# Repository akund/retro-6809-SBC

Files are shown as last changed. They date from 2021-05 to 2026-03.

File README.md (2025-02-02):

# retro-6809-SBC
6809 based single board computer (more product info on [Tindie](https://www.tindie.com/products/akund/bare-retro-6809-sbc-pcb-only/))

This library is free software. - WITHOUT ANY WARRANTY -

2018-2023 Adrian Kundert. [adrian.kundert@gmail.com](mailto:adrian.kundert@gmail.com)  

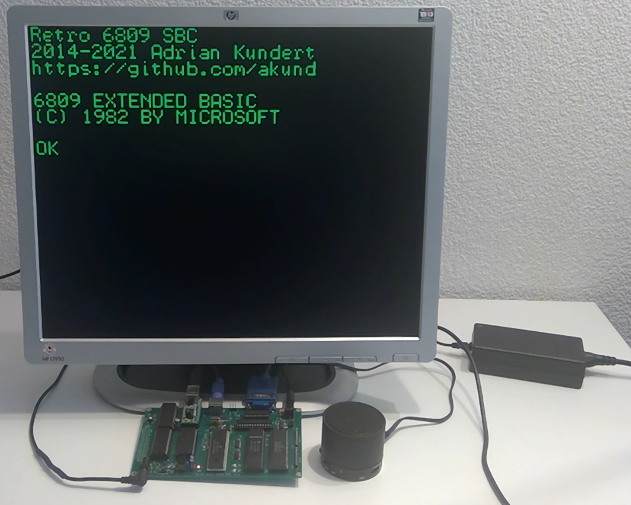
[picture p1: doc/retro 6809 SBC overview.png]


The [retro 6809 SBC](doc/Retro_6809_SBC.pdf) is a homebrew 8-bit computer running BASIC as in the 80's but with sound and more modern peripherals like PS/2 keyboard, VGA output and SD card.
The system has 32 KB RAM for a MPU clocked at 8 MHz. The Audio/Video and Keyboard peripherals are implemented by an ATmega328 ([APL](https://github.com/akund/APL)).

# Features Overview
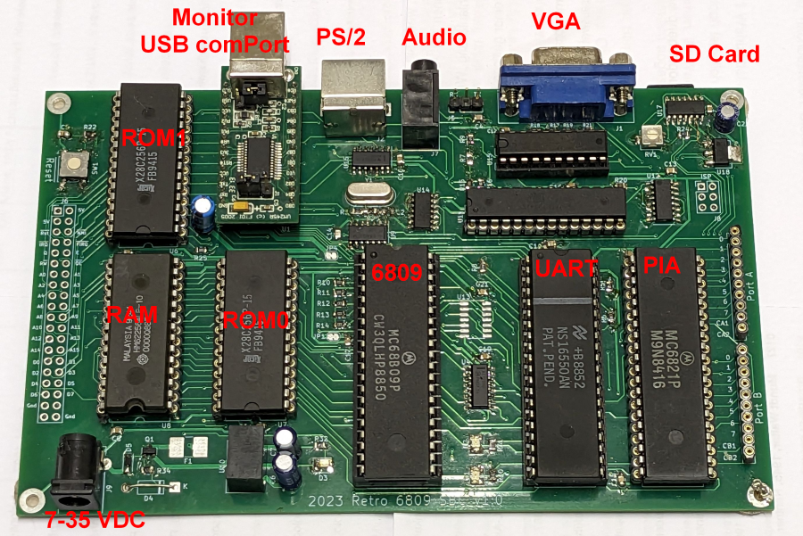
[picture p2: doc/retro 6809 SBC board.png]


# Demo

## Microsoft Color Computer Extended Basic (reworked source code based on [Grant Searle](http://searle.x10host.com/6809/Simple6809.html)) .
## Color Computer Disk Basic (the FAT32 SD card implmentation is based on CC Dharmani ExploreEmbedded) 
### Included tokens
#### (From the Color BASIC ROM)

FOR, GO, REM, ELSE, IF, DATA, PRINT, ON GOSUB, ON GOTO, INPUT, LINE INPUT, END, NEXT, DIM, READ, RUN, RESTORE, RETURN, STOP, POKE, CONT, LIST, CLEAR, SET, CLS, SOUND, NEW, EXEC, TAB, TO, SUB, THEN, NOT, STEP, +, -, *, /, ^, AND, OR, >, =, <

#### (From the Extended BASIC ROM)

DEL, DEF, LET, RENUM, FN, USING, &, &H, TRON, TROFF, EDIT

#### (From the Disk BASIC ROM)

DIR, LOAD, SAVE, KILL

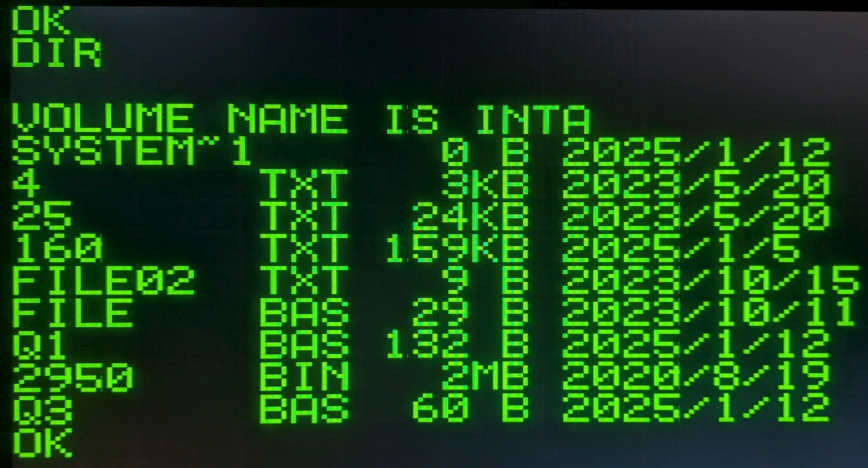
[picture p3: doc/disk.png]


#### (added to the BASIC commands)

DATE, TIME

### Secondary functions

#### (From the Color BASIC ROM)
SGN, INT, ABS, USR, RND, SIN, PEEK, LEN, STR$, VAL, ASC, CHR$, LEFT$, RIGHT$, MID$, INKEY$, MEM

#### (From the Extended BASIC ROM)
ATN, COS, TAN, EXP, FIX, LOG, SQR, HEX$, VARPTR, INSTR, STRING$, MID$ (MODIFICATION), POS

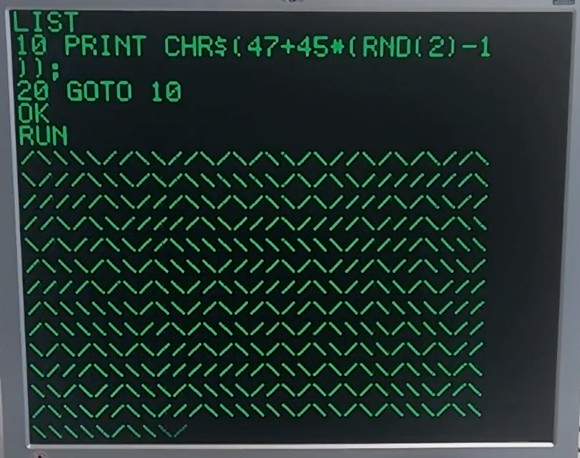
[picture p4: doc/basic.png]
[](https://www.youtube.com/watch?v=NazOm493rk8)

The BASIC commands can be entered with the keyboard at the prompt or from Terminal (see below)

## Monitor usage with the Terminal
The Monitor is an assistance tool for debugging by accessign the memory and sending BASIC command (override the keyboard).
By the Terminal command "h\r" the Help Menu is shown.
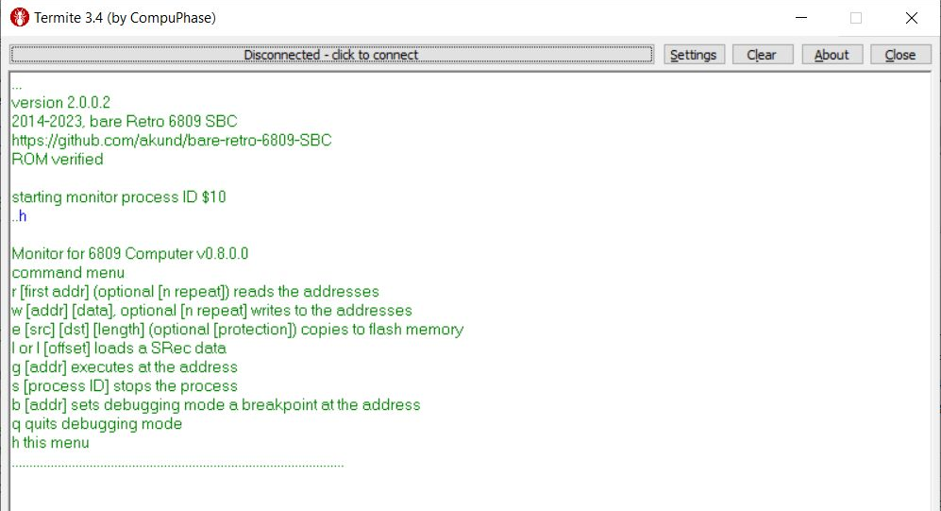
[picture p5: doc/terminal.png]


1. A [BASIC file](basic/pong.bas) can be send to the retro 6809 SBC with the command "L"
a message "send now the BAS file" is prompt before you can send the BASIC file.

2. A SREC file can be loaded in the memory with the command "l\r" and then execute "g\r".
Important when another program is loaded, the command "S 20\r" is required free the RAM occupied by the BASIC process (ID 0x20).
As an example, the program [SOKOBAN](app/sokobanC.s19) starting at adress 0x2000 is loaded ("l\r") into the RAM and executed ("g 2000\r").
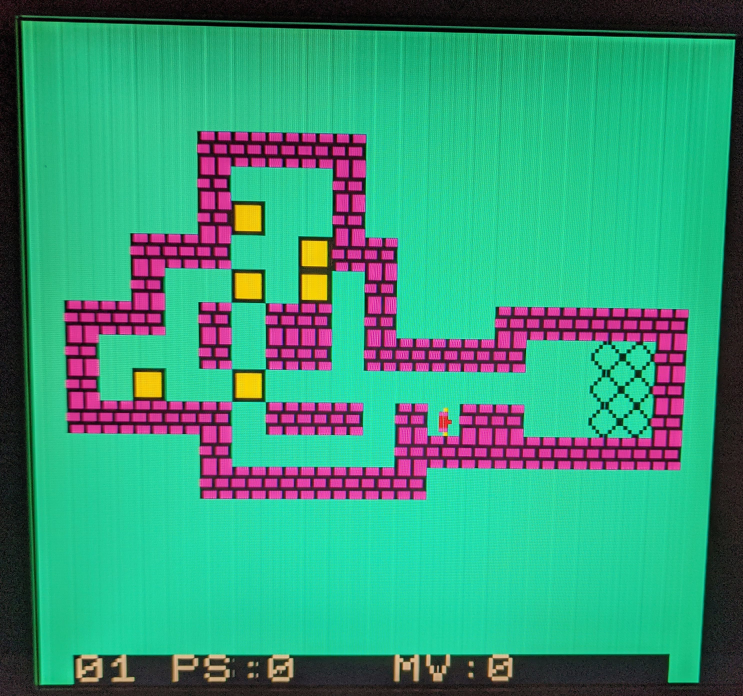
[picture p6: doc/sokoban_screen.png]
[](https://www.youtube.com/watch?v=ke1KYbIA_8k)

Another example, the demo program [SD_CARD](app/demoSD_C.s19) starting at adress 0x2000 is loaded ("l\r") into the RAM and executed ("g 2000\r").

main() {

	char* pData, filename; 
	if(initDISK() != 0) return;	
	dir();	
	filename = "FILE.TXT";
	pData = "hello SDcard";
	writefile(filename, pData);
	readfile(filename);
	deletefile(filename);
}

## C cross-compiler
The PC application "mc.exe" is an ANSI C89 cross-compiler for program written in C targeting the 6809 MPU.

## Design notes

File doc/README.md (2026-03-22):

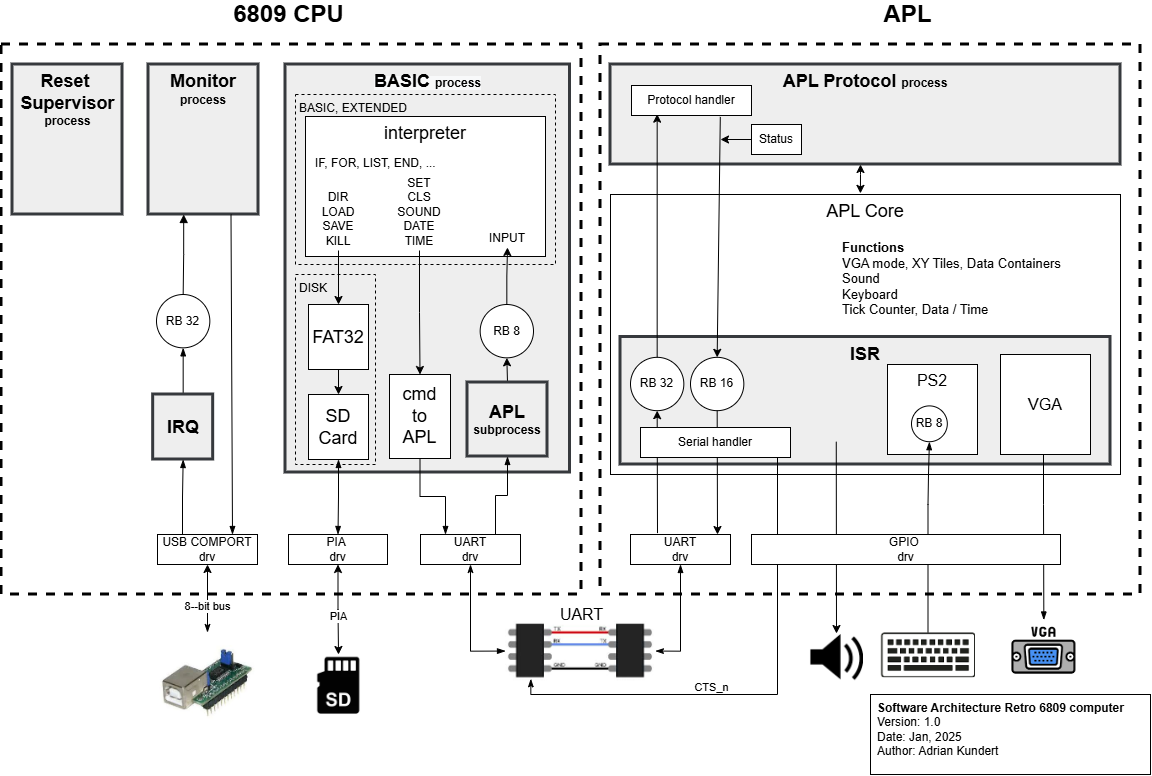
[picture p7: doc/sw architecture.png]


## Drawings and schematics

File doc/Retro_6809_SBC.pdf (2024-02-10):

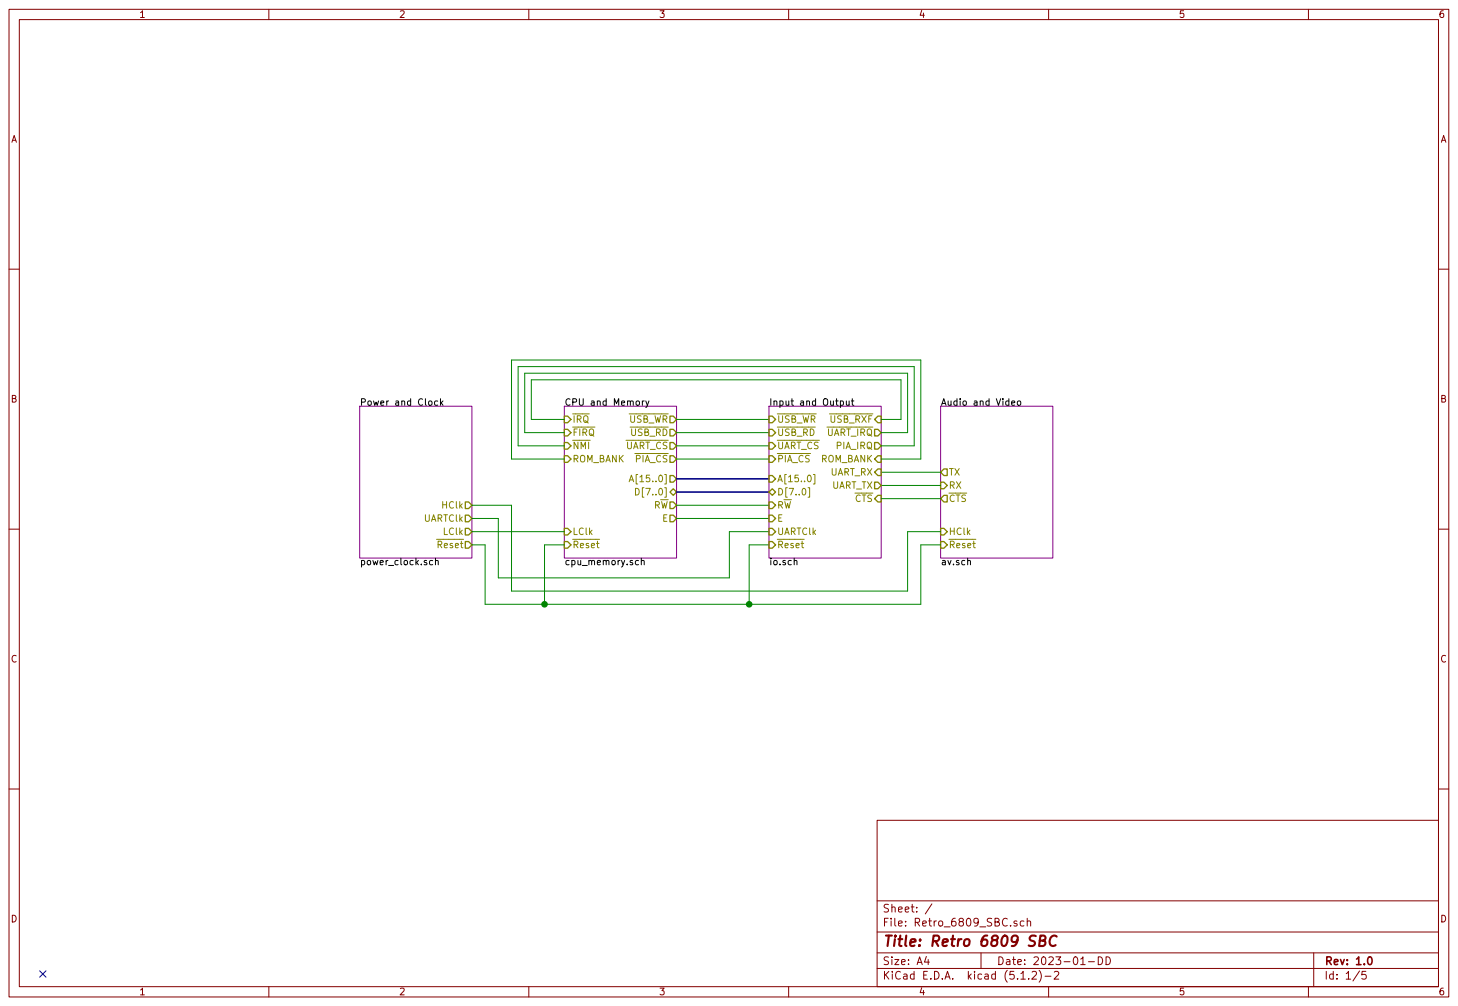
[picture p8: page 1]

TXHClk CTS
av.sch Reset RX

File: Retro_6809_SBC.sch Sheet: /
Id: 1/5 Title: Retro 6809 SBC

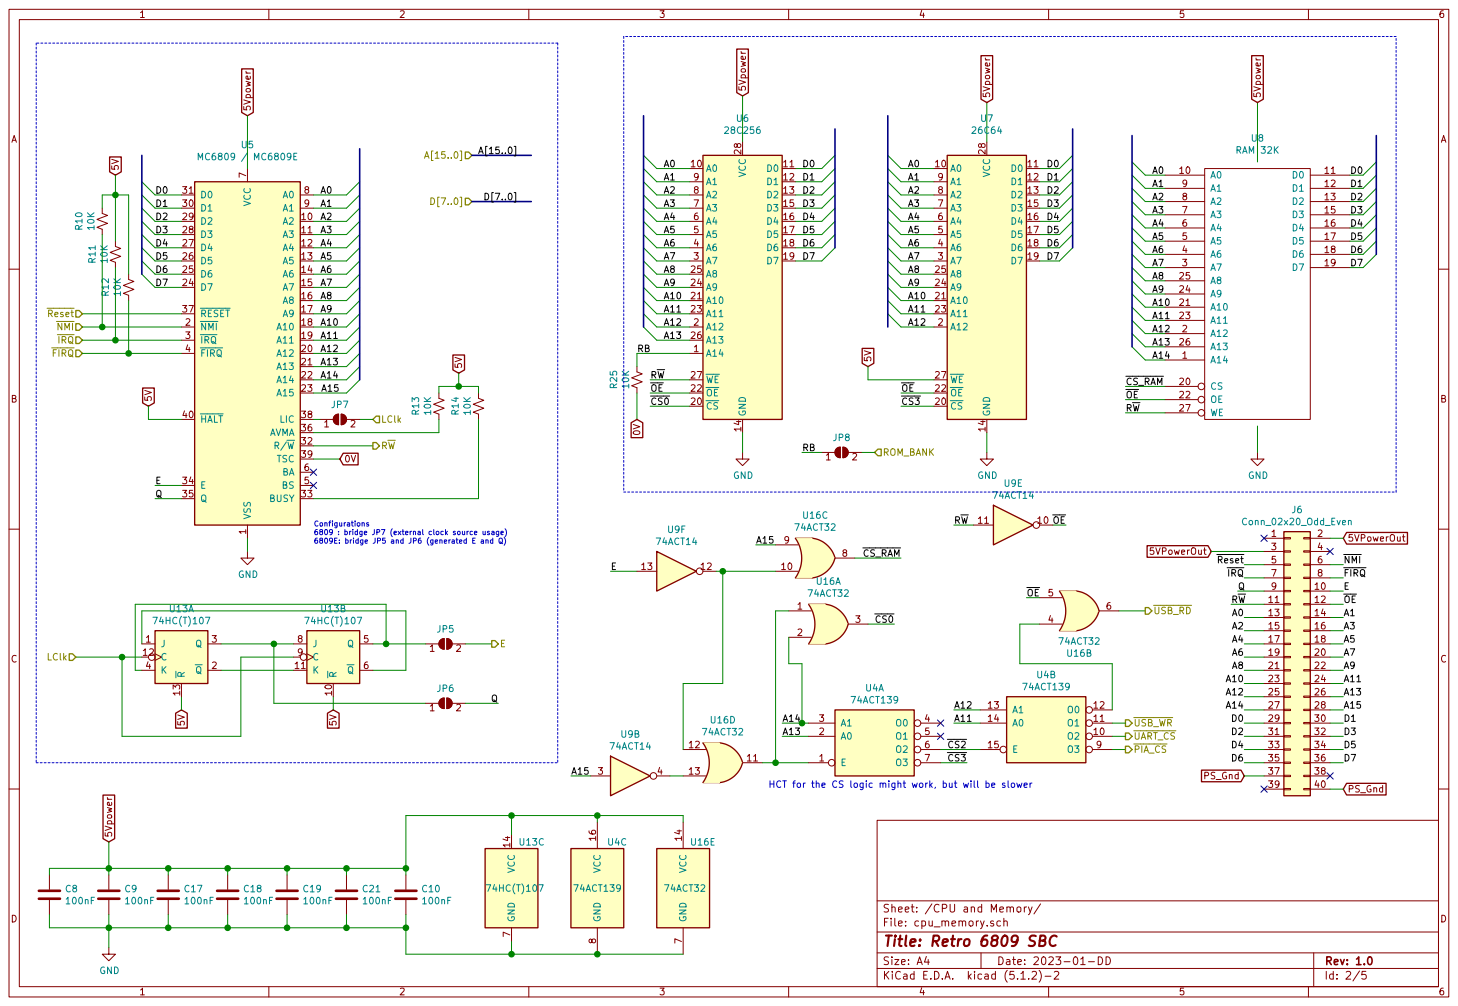
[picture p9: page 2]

HCT for the CS logic might work, but will be slower C8

Sheet: /CPU and Memory/
File: cpu_memory.sch
Id: 2/5 Title: Retro 6809 SBC

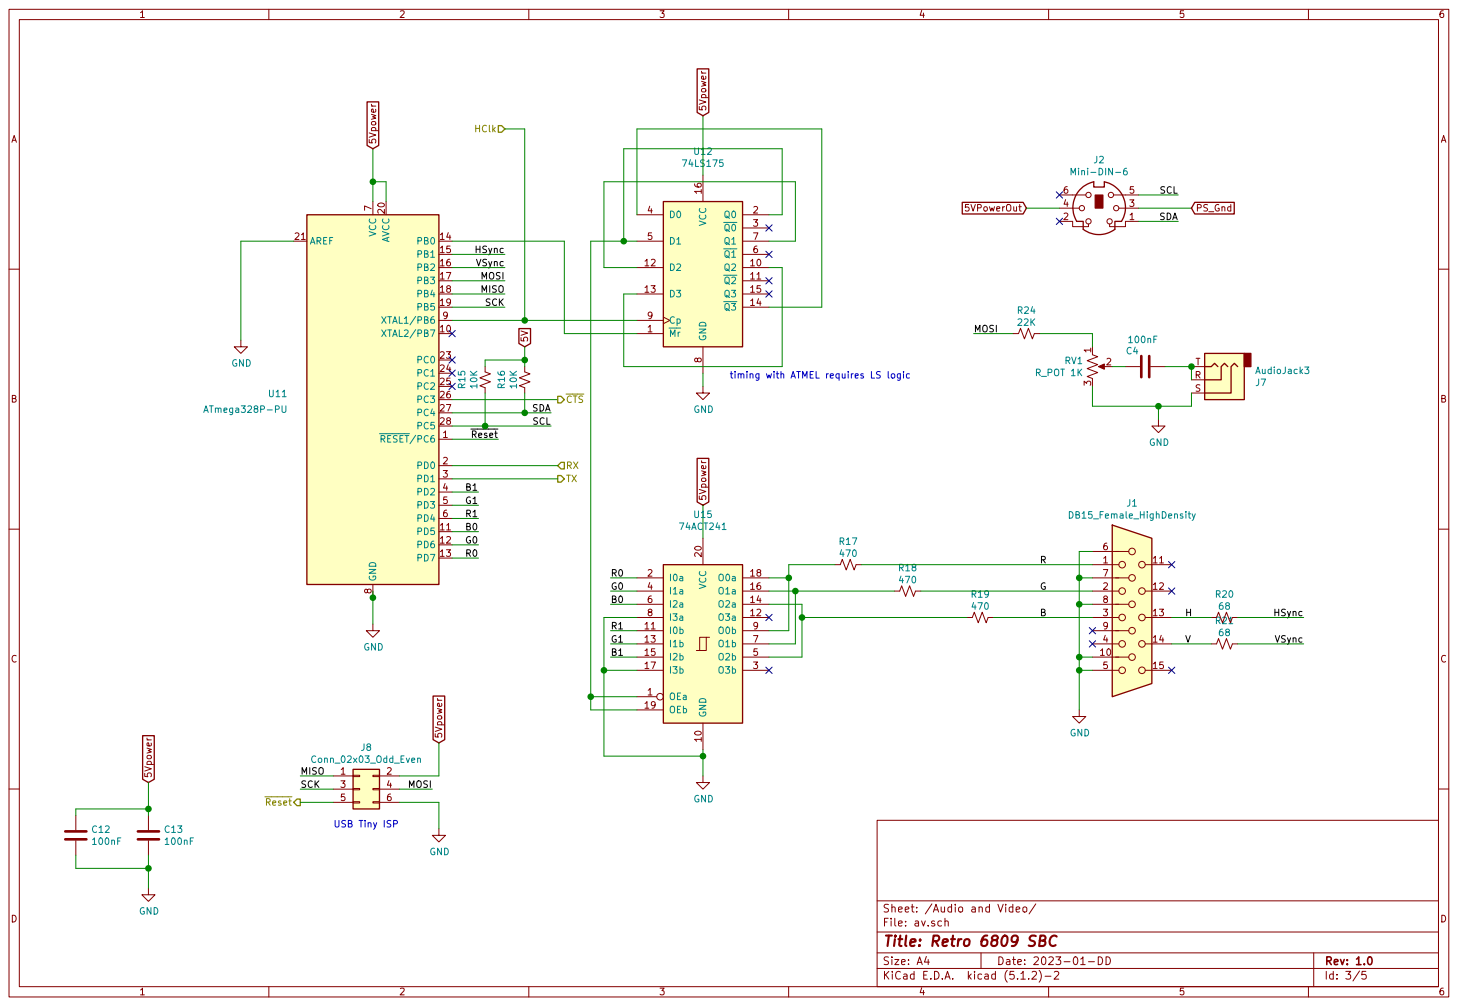
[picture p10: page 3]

8 XTAL1/PB6 9 U11 ATmega328P-PU Mr 1 Q2 10 Q2 11 D2 12 D3 13 Q3 14 Q3 15 VCC 16 Q0 2 Q0 3 D0 4 D1 5 Q1 6 Q1 7 GND

timing with ATMEL requires LS logic

File: av.sch Sheet: /Audio and Video/
Id: 3/5 Title: Retro 6809 SBC

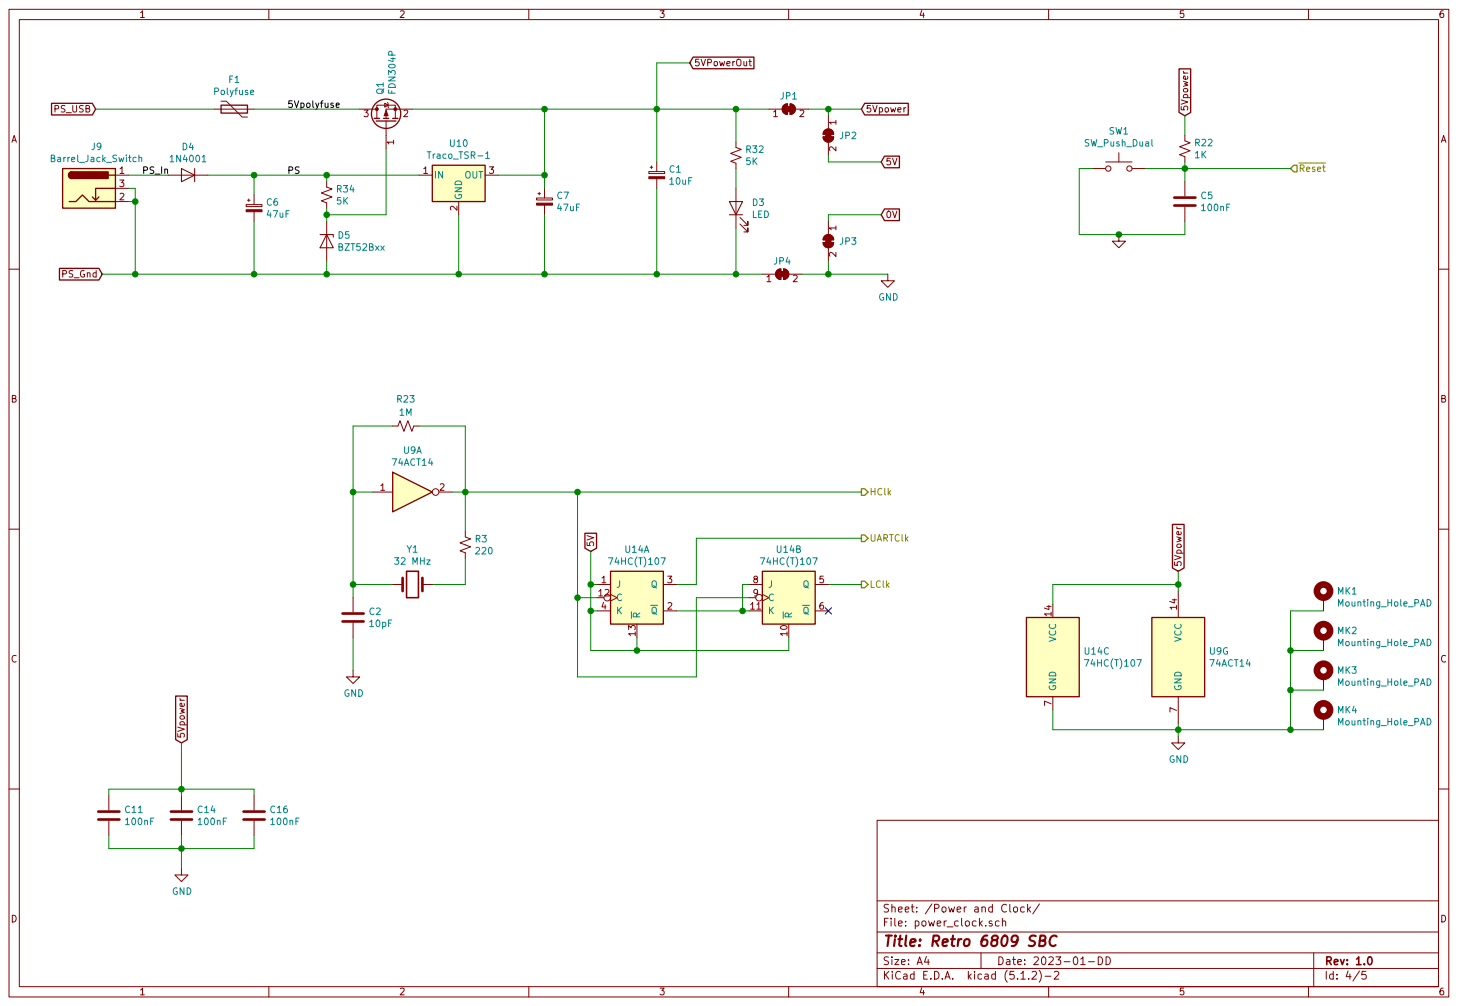
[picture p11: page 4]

File: power_clock.sch Sheet: /Power and Clock/
Id: 4/5 Title: Retro 6809 SBC

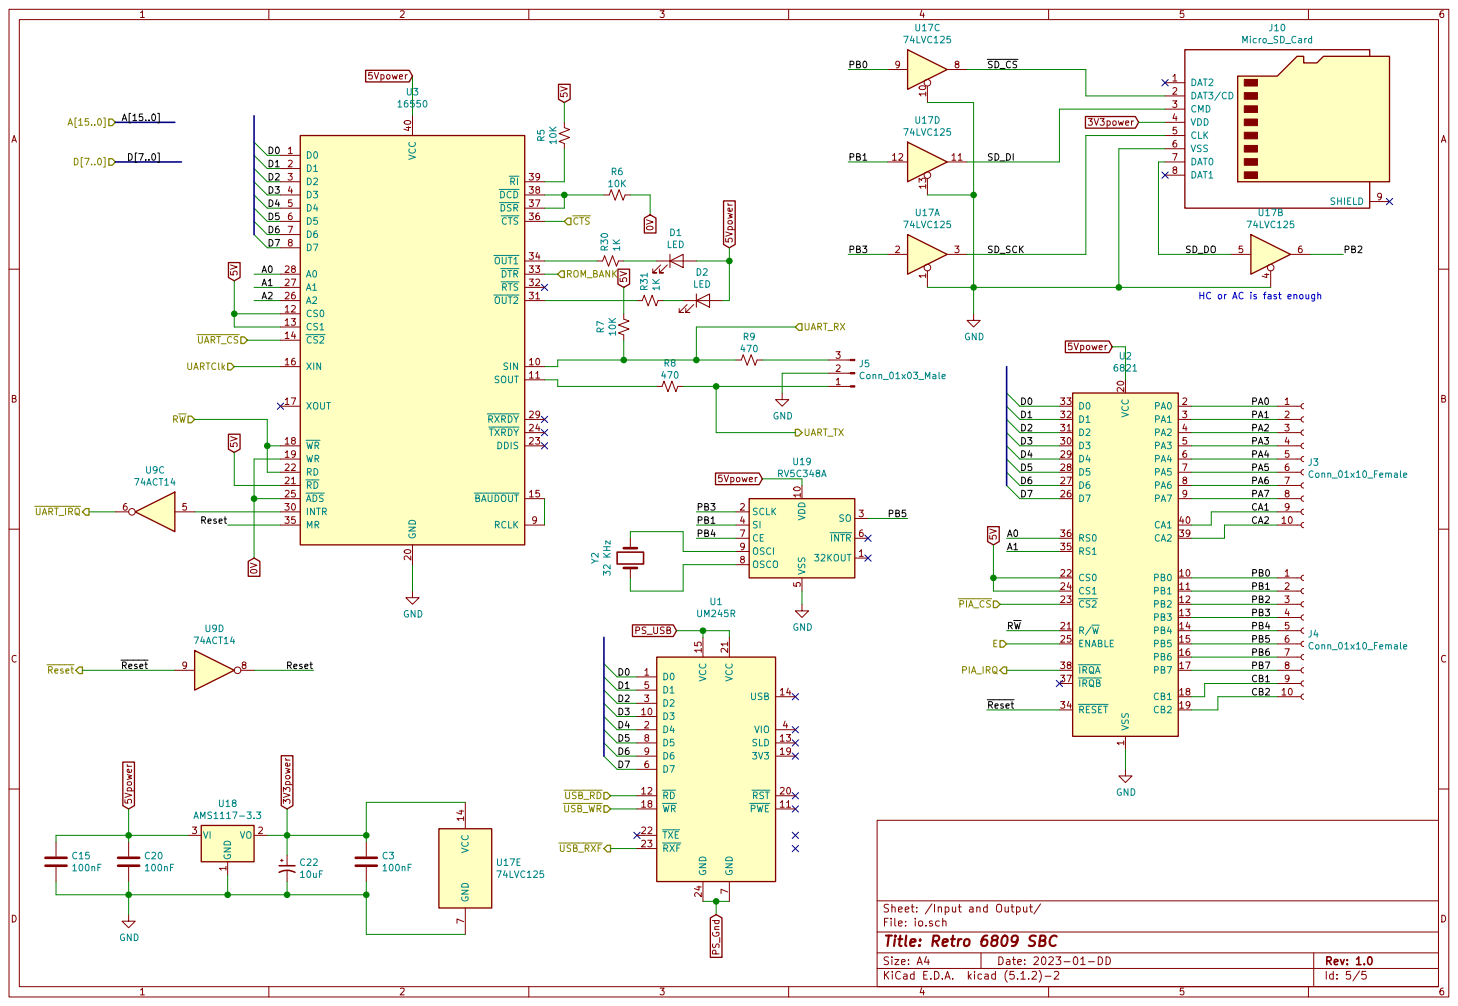
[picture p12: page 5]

HC or AC is fast enough

File: io.sch Sheet: /Input and Output/
Id: 5/5 Title: Retro 6809 SBC

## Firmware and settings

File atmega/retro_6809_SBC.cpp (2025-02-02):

/***************************************************************************************************/
/*                                                                                                 */
/* file:          retro_6809_SBC.ino                                                               */
/*                                                                                                 */
/* source:        2020, written by Adrian Kundert (adrian.kundert@gmail.com)                       */
/*                                                                                                 */
/* description:   Retro 6809 SBC application                                                       */
/*                                                                                                 */
/* This library is free software; you can redistribute it and/or modify it under the terms of the  */
/* GNU Lesser General Public License as published by the Free Software Foundation;                 */
/* either version 2.1 of the License, or (at your option) any later version.                       */
/*                                                                                                 */
/* This library is distributed in the hope that it will be useful, but WITHOUT ANY WARRANTY;       */
/* without even the implied warranty of MERCHANTABILITY or FITNESS FOR A PARTICULAR PURPOSE.       */
/* See the GNU Lesser General Public License for more details.                                     */
/*                                                                                                 */
/***************************************************************************************************/

#include "config.h"
#include "APLcore.h"
#include "APLtile.h"
#ifdef ATMEL_STUDIO
	#include <avr/pgmspace.h>
	#include <avr/io.h>
	#include <avr/boot.h>
	#include <avr/interrupt.h>
#endif


#pragma GCC optimize ("-O3") // speed optimization gives more deterministic behavior

BOOTLOADER_SECTION void boot_program_page(unsigned long int page, unsigned char *buf); // declared as unrewritable section

const char SwVersion[] PROGMEM = "sw v1.2.0.0\r";

APLcore INSTANCE;
APLcore* pAPL = 0;

const uint8_t Container_Size = TileMemSize;

// programmable PGM tiles for custom rendering
const uint8_t PGM_Container_index_OFFSET = 0x80;
const uint8_t PGM_Container_COUNT = 32;
const unsigned char PGM_Container[PGM_Container_COUNT*Container_Size] __attribute__((aligned(SPM_PAGESIZE))) PROGMEM = {};

// programmable RAM tiles for custom rendering
const uint8_t RAM_Container_index_OFFSET = 0xE0;
const uint8_t RAM_Container_COUNT = 10;
uint8_t RAM_Container[RAM_Container_COUNT][Container_Size];

uint8_t  tileScroll, x, y, MAX_X, MAX_Y;
bool textMode;

// screen cursor state
#define CURSOR_BLINKING 'b'
#define CURSOR_ON       '1'
#define CURSOR_OFF      '0'

// keyboard data
#define KB_DATA 3
char kbStr[6];

// APL status
#define APL_RESET     '0'
#define APL_READY     '1'
#define APL_BUSY      '2'
#define APL_UNDEFINED '9'
#define APL_STATUS_BYTE 2
char statusStr[5];
unsigned long t;
    
/*
 * Protocol format
[Direction ][ body ][ end]
['D' or 'U' ]  [ body]  [ '\r' ]

Body [cmd] [len] [data ....]
video command(s)
  - Cursor blink/on/off -> 'c', ('b' or '1' or '0'), '\r'
  - Position xy         -> 'p', x+'0', y+'0', '\r'     
  - scRoll              -> 'r', n+'0', '\r'            
  - putFontchar         -> 'f', length, value0, value1, ... value_length-1, '\r'
  - cLearscreen         -> 'l', color+'0', '\r'
  - setTile             -> 't', length+'0', index0, index1, ... , index_length-1, '\r'	; PETSCII character set (index 0 to 0x7f) or programable tile (index >=0x80 for PGM, index >= 0xe0 for RAM)
  - containerData       -> 'd', length+'0', index, data0, data1, ... data_length-1, '\r'; programable 32 PGM tiles (index >=0x80) or 10 RAM tiles (index >= 0xe0) for video or sound.
  - piXelscrolling xy   -> 'x', x+'0', y+'0', '\r'										; Graphmode only. The x/y values are 0, 2, 4 or 6)
  
audio command(s)
  - tOne                -> 'o', tone, duration, '\r' (tone in f/4 Hz, duration in 1/10 Sec)
  - setSound            -> 's', index, '\r'												; activate the sound to the given data index

keyboard command(s)
  - Key pressed			->  'k', length, value(s) ....., '\r'

date and time commands
  - dAte                -> 'a', YY+'0, MM+'0, DD+'0, '\r'
  - tIme                -> 'i', HH+'0, MM+'0, SS+'0, '\r'
  - timestaMp			-> 'm', (7/4/5 bits, word for year-since-1980/month/day),		; Count of years from 1980 in range of from 0 to 127 (1980-2107), Month of year in range of from 1 to 12, Day of month in range of from 1 to 31.
							(5/6/5 bits, word for hour/minutes/doubleseconds), 			; Hours in range of from 0 to 23, Minutes in range from 0 to 59, 2 second count in range of form 0 to 29 (0-58 seconds).
						    '\r' 
  
APL status command(s)
  - stAtus				-> 'a', status (0:reset, 1:ready, 2:busy), '\r'
  
------------------------- Example -------------------------------------
To APL    ->  'D', cmd, len, data ..., '\r'
From APL  ->  'U', cmd, len, data ...  '\r'
-----------------------------------------------------------------------  
*/
#define ReceiveTimeOut 250

#pragma GCC push_options
#pragma GCC optimize ("O0") // avoid optimization to ensure volatile variable proprieties

bool waitReceived(uint8_t  cnt) {
	unsigned long t = pAPL->ms_elpased()+ReceiveTimeOut;
	uint8_t  receivedCnt;
	do {		
		receivedCnt = pAPL->UARTcountRX();
	} while ((receivedCnt < cnt) && (t > pAPL->ms_elpased()));
	return (receivedCnt >= cnt) ? true:false;
}

void updateRAM_Container(uint8_t* src, uint8_t* dst) {	// function to avoid gcc memcpy
	for (uint8_t  n = 0; n < Container_Size; n++) {   
		*dst++ = *src++;	// copy byte by byte to ensure atomic operation
	}
}
#pragma GCC pop_options

// draw the char on the screen (text mode only)
void printScreen(char c) {
    uint8_t  old_y = y;
    switch(c){
    case '\r':  	// carriage return 0x0d
         pAPL->setTileXYtext(x, y, ' '); // clear cursor
         x = 0; y++; //implicitly includes a LF
        break;
    case '\b':  	// backspace 0x08
        pAPL->setTileXYtext(x, y, ' '); // clear cursor
        if(x > 0) pAPL->setTileXYtext(--x, y, ' ');
        break;
    default:
        pAPL->setTileXYtext(x, y, c);  // overwrite cursor
        x++;
    }   
    
    // update the index
    if (x >= MAX_X) {x=0; y++;}
    if (y >= MAX_Y) {y=0; tileScroll=0;} // scrolling can begin

    // once the bottom reached, scroll when the line has changed
    if ((old_y != y) && (tileScroll != 0xff)) { 
        if (++tileScroll >= MAX_Y) tileScroll=0;
        pAPL->setTileScroll(tileScroll); // scroll y instead
        // delete the scrolled down line
        for (uint8_t  n = 0; n < MAX_X; n++) {    
            pAPL->setTileXYtext(n, y, ' ');
        }
    }
    pAPL->setCursorXY(x, y); // update the position
}

void sendTimeStamp() {
	
	pAPL->UARTwrite('U');
	pAPL->UARTwrite('m');
	unsigned int i = pAPL->GetDateF32();
	pAPL->UARTwrite(char(i >> 8));
	pAPL->UARTwrite(char(i & 0xff));
	i = pAPL->GetTimeF32();
	pAPL->UARTwrite(char(i >> 8));
	pAPL->UARTwrite(char(i & 0xff));
	pAPL->UARTwrite('\r');
}

int main() {
  
	tileScroll = 0xff;  // disabled value
	t = x = y = 0;
	kbStr[0]='U';     kbStr[1]='k';       kbStr[2]='1';   kbStr[KB_DATA]=' ';   kbStr[4]='\r';     kbStr[5]=0;
	statusStr[0]='U'; statusStr[1]='a';   statusStr[APL_STATUS_BYTE]=APL_RESET; statusStr[3]='\r'; statusStr[4]=0;
	pAPL = &INSTANCE; //APLcore::instance();  
	pAPL->coreInit();	// default initialization in text mode
	textMode = true;
	MAX_X = pAPL->getscrViewWidthInTile();
	MAX_Y = pAPL->getscrViewHeightInTile();
	pAPL->UARTsetBaudrate(57600); //baud rate for the APL UART
	pAPL->UARTwrite((PGM_P)SwVersion);
	
	// send first APL status after booting-up
	pAPL->UARTwrite(statusStr);
	statusStr[APL_STATUS_BYTE] = APL_READY;
	pAPL->UARTwrite(statusStr);

	while(1) {
		//-------------------------------------- INPUTS PROCESSING ------------------------------------------------//
		if (pAPL->UARTavailableRX() == true) {
			// read the next key  
			char c = pAPL->UARTread();
			//pAPL->UARTwrite(c);  

			// protocol handling  
			if (c == 'D') {
				// download msg found
				if (waitReceived(1) == true) {
					// get the command	
					switch (pAPL->UARTread()) {
					case 'c':   // cursor on screen state command
					{
						if (waitReceived(1) == false) break;
						uint8_t  sts = pAPL->UARTread(); // extract the status
						if (waitReceived(1) == false) break;
						if(pAPL->UARTread() == '\r') { // get the CR
							//if((sts == CURSOR_BLINKING) || (sts == CURSOR_ON) || (sts == CURSOR_OFF)) cursorState = sts;
							pAPL->setCursor(x,y,(sts == CURSOR_BLINKING)?true:false);
							//pAPL->UARTwrite("cursor");
						}						
					}
					break;
					case 'f':   // print char on screen command
					{
						if (waitReceived(1) == false) break;
						uint8_t  len = pAPL->UARTread() - '0'; // extract the len
						if((len >= 1) && (len <= 16)) {
							char c[16];
							for (uint8_t  n = 0; n < len; n++) {   
								if (waitReceived(1) == false) break;
								c[n] = pAPL->UARTread(); // extract the char
							}
							if (waitReceived(1) == false) break;
							if(pAPL->UARTread() == '\r') {// get the CR              
								if (textMode != true) {
									textMode = true;
									pAPL->initScreenBuffer(TextMode);
									MAX_X = pAPL->getscrViewWidthInTile();
									MAX_Y = pAPL->getscrViewHeightInTile();
									tileScroll = 0xff;  // disabled value
									x = y = 0;
								}
								for (uint8_t  n = 0; n < len; n++) {
									printScreen(c[n]); 
								}
							}
						}						
					}
					break;
					case 't':   // print tile on screen command
					{
						if (waitReceived(1) == false) break;
						uint8_t  len = pAPL->UARTread() - '0'; // extract the len
						if((len >= 1) && (len <= TileMemSize)) {							
							uint8_t tmp_data[TileMemSize];
							for (uint8_t  n = 0; n < len; n++) {   
								if (waitReceived(1) == false) break;
								tmp_data[n] = pAPL->UARTread(); // extract the char
							}
							if (waitReceived(1) == false) break;
							if(pAPL->UARTread() == '\r') {// get the CR              
								if (textMode == true) {
									textMode = false; pAPL->initScreenBuffer(GraphMode);
									MAX_X = pAPL->getscrViewWidthInTile();
									MAX_Y = pAPL->getscrViewHeightInTile();
									pAPL->setTileScroll(0); tileScroll = 0xff; // tile scrolling back to 0 and disabled
									x = y = 0;
								}
								for (uint8_t  n = 0; n < len; n++) {
									uint8_t  tileIndex = tmp_data[n];
									if (tileIndex < PGM_Container_index_OFFSET) pAPL->setTileXY(x++, y, (uint8_t*)&PETtile4B[TileMemSize * tileIndex]);
									else {
										if (tileIndex < RAM_Container_index_OFFSET) {
											tileIndex -= PGM_Container_index_OFFSET;	// remove the offset
											if (tileIndex < PGM_Container_COUNT) pAPL->setTileXY(x++, y, (uint8_t*)&PGM_Container[TileMemSize * tileIndex]);											
										}									
										else {
											tileIndex -= RAM_Container_index_OFFSET;	// remove the offset
											if (tileIndex < RAM_Container_COUNT) pAPL->setRAMTileXY(x++, y, RAM_Container[tileIndex]);
										}
									}
									// update the index
									if (x >= MAX_X) {x=0; y++;}
									if (y >= MAX_Y) {y=0;}
								}
							}
						}						
					}
					break;
					case 'd':   // container data command
					{
						if (waitReceived(1) == false) break;
						uint8_t  len = pAPL->UARTread() - '0'; // extract the len					
						if (waitReceived(1) == false) break;						
						uint8_t tileIndex = pAPL->UARTread(); // extract the container index					
						if((len >= 1) && (len <= Container_Size)) {
							uint8_t tmp_data[TileMemSize];
							for (uint8_t n = 0; n < len; n++) {   
								if (waitReceived(1) == false) break;
								tmp_data[n] = pAPL->UARTread(); // extract the values								
							}
							if (waitReceived(1) == false) break;
							if(pAPL->UARTread() == '\r') {// get the CR              
								if (tileIndex >= PGM_Container_index_OFFSET) {
									if (tileIndex < RAM_Container_index_OFFSET) {
										tileIndex -= PGM_Container_index_OFFSET;
										if (tileIndex < PGM_Container_COUNT) {
											// write in PGM memory (slow)							
											uint8_t data[SPM_PAGESIZE];
											unsigned int offset = (unsigned int)Container_Size * (unsigned int)tileIndex;
											uint8_t* addr = (uint8_t*)PGM_Container + offset;										
											addr = (unsigned char*)((unsigned int)addr & 0xff80); // page base addr										
											for(uint8_t n=0; n < SPM_PAGESIZE; n++) { // Load a full data page current value
												data[n] = pgm_read_byte(addr++);
											}
											offset = offset & 0x7f;
											for(uint8_t n=0; n < Container_Size; n++) {
												data[offset++] = tmp_data[n];	// change wall tile value
											}																			
											boot_program_page((uint32_t)PGM_Container, data); // the flash write blocks the APL engine (approx 1 sec VGA screen off)									
										}
									}
									else {										
										tileIndex -= RAM_Container_index_OFFSET;
										if (tileIndex < RAM_Container_COUNT) updateRAM_Container(tmp_data, RAM_Container[tileIndex]);										
									}
								}
							}						
						}
					}
					break;
					case 'l':   // cLear screen command
					{
						if (waitReceived(1) == false) break;
						pAPL->UARTread() - '0'; // extract the color value
						if (waitReceived(1) == false) break;
						if(pAPL->UARTread() == '\r') { // get the CR
							pAPL->initScreenBuffer();							
							x = y = 0;
							if(tileScroll != 0xff) {
								pAPL->setTileScroll(0); tileScroll = 0xff; // tile scrolling back to 0 and disabled
							}
							//pAPL->UARTwrite("cls");
						}
					}
					break;
					case 'p':   // position x,y command
					{
						if (waitReceived(1) == false) break;
						uint8_t  xPos = pAPL->UARTread(); // extract the x value
						if (waitReceived(1) == false) break;
						uint8_t  yPos = pAPL->UARTread(); // extract the y value						
						if (waitReceived(1) == false) break;
						if(pAPL->UARTread() == '\r') { // get the CR
							if((xPos >= '0') && (xPos-'0' < MAX_X) && (yPos >= '0') && (yPos-'0' < MAX_Y)) {
								x = xPos-'0'; y = yPos-'0';
								if(tileScroll != 0xff) {
									y += tileScroll;	// consider the scrolling when enabled
									if (y >= MAX_Y) y -= MAX_Y;
								}
							}
						}						
					}
					break;
					case 'r':   // scRoll screen command
					{
						if (waitReceived(1) == false) break;
						uint8_t  nLine = pAPL->UARTread(); // extract the value
						if (waitReceived(1) == false) break;
						if((nLine >= '0') && (pAPL->UARTread() == '\r')) { // get the CR
							tileScroll = nLine - '0';
							pAPL->setTileScroll(tileScroll);  //TBD full height
							//pAPL->UARTwrite(nLine);						
						}
					}
					break;
					case 'o':   // tOne command
					{
						if (waitReceived(1) == false) break;
						uint8_t  pitch = pAPL->UARTread(); // extract the value
						if (waitReceived(1) == false) break;
						uint8_t  duration = pAPL->UARTread(); // extract the value
						if (waitReceived(1) == false) break;
						if(pAPL->UARTread() == '\r') {
							while(pAPL->setTone(pitch, duration) == false);
						}
					}
					break; 
					case 's':   // Sound command
					{
						if (waitReceived(1) == false) break;
						uint8_t  index = pAPL->UARTread() - '0'; // extract the RAM container index
						if (waitReceived(1) == false) break;
						if(pAPL->UARTread() == '\r') {// get the CR              
							if (index < RAM_Container_COUNT) {
								while(pAPL->setRAMSound(RAM_Container[index]) == false);                                
								//pAPL->UARTwrite("snd");                                
							}
						}
					}
					break;
					case 'x':   // pixel scrolling x,y command
					{
						if (waitReceived(1) == false) break;
						uint8_t  xPos = pAPL->UARTread(); // extract the x value
						if (waitReceived(1) == false) break;
						uint8_t  yPos = pAPL->UARTread(); // extract the y value
						if (waitReceived(1) == false) break;
						if(pAPL->UARTread() == '\r') { // get the CR
							if((xPos >= '0') && (xPos-'0' < TileMemHeight) && (yPos >= '0') && (yPos-'0' < TileMemHeight)) {
								pAPL->setXScroll((xPos-'0') & 0b110);  // only even values
								pAPL->setYScroll(yPos-'0');
							}
						}
					}
					break;
					case 'a':   // date command
					{
						if (waitReceived(1) == false) break;
						uint8_t yy = pAPL->UARTread() - '0'; // extract the year value
						if (waitReceived(1) == false) break;
						uint8_t mm = pAPL->UARTread() - '0'; // extract the month value
						if (waitReceived(1) == false) break;
						uint8_t dd = pAPL->UARTread() - '0'; // extract the day value
						if (waitReceived(1) == false) break;
						if(pAPL->UARTread() == '\r') {		 // get the CR
							if((mm != 0) && (dd != 0)) pAPL->setDate(yy, mm, dd);  // validate (only month and day cannot be 0) because a setdate all zero values is to trigger the timestamp without changes.
							sendTimeStamp(); // send back the timestamp as confirmation
							//pAPL->UARTwrite("date");
						}
					}
					break;
					case 'i':   // time command
					{
						if (waitReceived(1) == false) break;
						uint8_t hh = pAPL->UARTread() - '0'; // extract the hour value
						if (waitReceived(1) == false) break;
						uint8_t mm = pAPL->UARTread() - '0'; // extract the minute value
						if (waitReceived(1) == false) break;
						uint8_t ss = pAPL->UARTread() - '0'; // extract the second value
						if (waitReceived(1) == false) break;
						if(pAPL->UARTread() == '\r') {		 // get the CR
							pAPL->setTime(hh, mm, ss);
							sendTimeStamp(); // send back the timestamp as confirmation
							//pAPL->UARTwrite("time");
						}
					}
					default: break;
					}
				}
			}
		}

		//-------------------------------------- OUTPUTS PROCESSING ------------------------------------------------//
		// keyboard handling
		if (pAPL->keyPressed() == true) {        
			kbStr[KB_DATA] = pAPL->keyRead();
			pAPL->UARTwrite(kbStr);
		}
	  
		// status (heart beat)  
		{
			unsigned long t_now = pAPL->ms_elpased();    
			if(t < t_now) {
				statusStr[APL_STATUS_BYTE] = APL_READY; //sts;
				pAPL->UARTwrite(statusStr);
				t = t_now + 1000; // default 1000 ms periodic refresh
			}
		}
	}
}

#pragma GCC push_options
#pragma GCC optimize ("O0")		// otherwise the bootloader section is removed

// avr/boot.h documentation example
BOOTLOADER_SECTION void boot_program_page(uint32_t page, uint8_t *buf)
{
	uint16_t i;
	uint8_t sreg;
				
	// Disable interrupts.
	sreg = SREG;
	cli();
	bool b = (PORTC & 0x08) ? true:false; // wait until CTS_n cleared by APL ISR
	if(b == false) PORTC |= 0x08;  // CTS_n set	
	
	eeprom_busy_wait ();
	boot_page_erase (page);
	boot_spm_busy_wait (); // Wait until the memory is erased.
	for (i=0; i<SPM_PAGESIZE; i+=2)
	{
		// Set up little-endian word.
		uint16_t w = *buf++;
		w += (*buf++) << 8;
		boot_page_fill (page + i, w);
	}
	boot_page_write (page); // Store buffer in flash page.
	boot_spm_busy_wait(); // Wait until the memory is written.
	// Reenable RWW-section again. We need this if we want to jump back
	// to the application after bootloading.
	boot_rww_enable ();
	if(b == false) PORTC &= 0xf7;  // CTS_n cleared
	sei();
	// Re-enable interrupts (if they were ever enabled).
	SREG = sreg;
}
// -- LSS file (assembled code)----------------------------------------------------
//  Idx Name          Size      VMA       LMA       File off  Algn
//  1 .bootloader   00000196  00007c00  00007c00  00004d0a  2**0
// --------------------------------------------------------------------------------
// is less than the 512 bytes bootloader space
#pragma GCC pop_options
